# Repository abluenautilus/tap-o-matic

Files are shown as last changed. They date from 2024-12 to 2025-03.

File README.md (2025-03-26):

# Tap-O-Matic

Modification of the delay created by Harry Richardson based on the source code from the Olivia Artz Time Machine

## BOM
 - 9 * Bournes sliders (PTL30-15R0-104B2).
 - 9 * B10K - Song Huei TALL Trimmer Potentiometer with Detent
 - 5 * B10K Alpha vertical 9mm pots with 6.35mm shaft
 - 19 * Thonkicon Mono Jacks
 - 2 * SaleCom ES-4 mini toggle switches
 - 1 * DG408 multiplexer
 - 3 * 4051 multiplexer
 - 9 * 820R resistors (exact value doesn't matter - these set the LED brightness. Anything between about 800 and 1000 ohms should be good).
 - 4 * 16-pin DIP sockets.
 - 5 * 100nF capacitors
 - 1 * Daisy Patch Submodule
 - 4 * 2x5 headers (to connect to the Daisy).
 - 1 * 2x5 power connector (with no shroud - there isn't room!)
 - Knobs to taste :-)

Thonk should be good for the pots, the tall trimmers with detents, and the jacks.

https://www.thonk.co.uk/shop/alpha-9mm-pots/ (B10K, Vertical mount)

https://www.thonk.co.uk/shop/ttpots/ (B10K, Get the ones with the centre detent!)

https://www.thonk.co.uk/shop/thonkiconn/

The hard one is the switches. I got mine from JPR Electronics, where I they call it the "IP67 vertical on-on" switch.

https://www.jprelec.co.uk//categories/components/switches-and-sensors/toggle-switches/salecom-es-40t-ip67-sealed-submin-toggle-switch/product/ip67-toggle-spdt-vertic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

The Daisy Submodule can be bought from Juno. It was actually cheaper to buy it from their Ebay store rather than their own website. Not sure if that's still the case.

https://www.ebay.co.uk/itm/405345530695

The rest are all generally available: Digikey, Mouser, RS, Farnell...

## Front Panel
I got mine made by MeFace in the UK: send an email with an attached PDF or SVG to sales@meface.co.uk for a quote.

The files are available here: https://github.com/cormallen/tap-o-matic/tree/main/panel

## Build Instructions
The components have to be soldered in the right order, since some of the components cover the solder holes of others.

### Back side components.
First solder all the components on the back side of the board:

 - List item
 - IC Sockets
 - Capacitors
 - Resistors (shown on the silkscreen as being on the front, but put them on the back!)
 - Headers
 - Power connector.

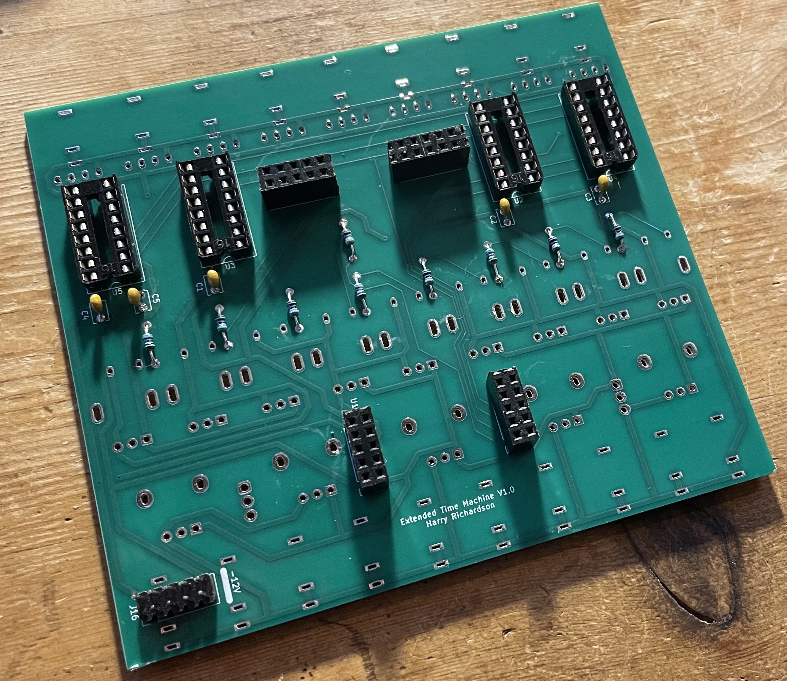
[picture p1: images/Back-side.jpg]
image info


This is how should look when you're done.

 ### Trim the ends

Because the sliders (and two jack sockets) go on top of backside components, you need to trim the ends that poke through to the front side as close to the board as is easily possible (just for those components that go under the sliders and jacks).

### Insulate

Next, we need to put some electrical tape (or other insulator) on the front side, so that the sliders and jacks don't touch any of our solder.

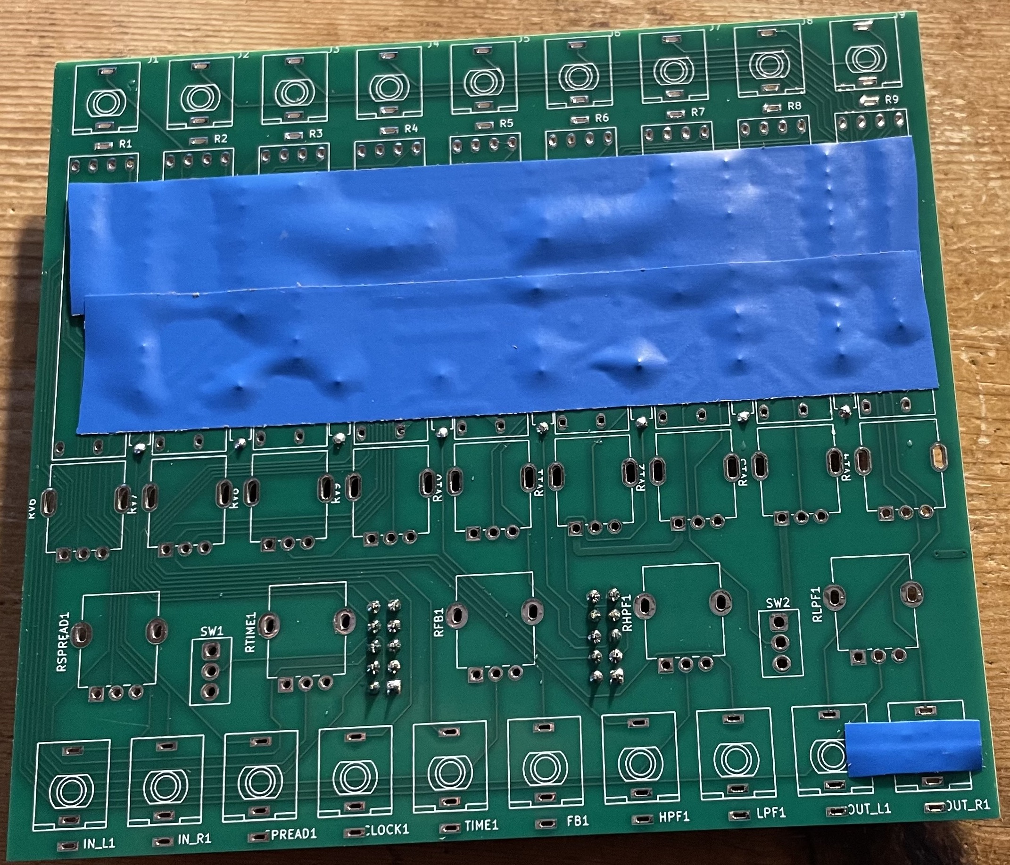
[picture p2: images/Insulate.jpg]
image info


### Jacks and Pan Pots

Place the jacks and pan pots in their holes. Put the front panel on them (to make sure everything is perfectly aligned), do up the nuts on the jacks to hold everything in place and then flip the board over so that you can solder it all in.

For the two jacks that go over the power connector, you may need to trim just a little bit of the plastic (less than 1mm!) out from the sides so that they can fit flush to the board. This can be done with a pair of dikes, a file or a dremmel.

Take the panel back off again.

### Sliders, Pots and Switches.

Place the rest of the front panel hardware on the board, put the front panel on, then flip it over and solder.

Note that the sliders are EXTREMELY close to the pan pots, as I was trying to give as much room for fingers on the main knobs as possible. According to the datasheets, this should have been fine, but **if I did another revision then I would move the pan pots down by 1mm (and update the front panel!)**. Fortunately the sliders actually have a good bit of play in them, so you should be able to get them in fine. (But make sure the pan pots are soldered first, since you need those to be perfectly aligned with the front panel holes).

## Flashing Firmware

You can download the firmware image here: https://github.com/cormallen/tap-o-matic/tree/main/binaries

You can flash the firmware either by setting up VSCode or by using the Web Programmer. VSCode is overkill unless you need a dev environment anyway, or you want to make changes to the code.

Instructions for the Web Programmer method: https://www.youtube.com/watch?v=UaUJ3N8i57c

Instructions for the VSCode method: https://github.com/electro-smith/DaisyWiki/wiki/1.-Setting-Up-Your-Development-Environment

*The video I've linked for the Web Programmer is for QuBit modules, but the process is identical, and that's the simplest explanation I could find.*

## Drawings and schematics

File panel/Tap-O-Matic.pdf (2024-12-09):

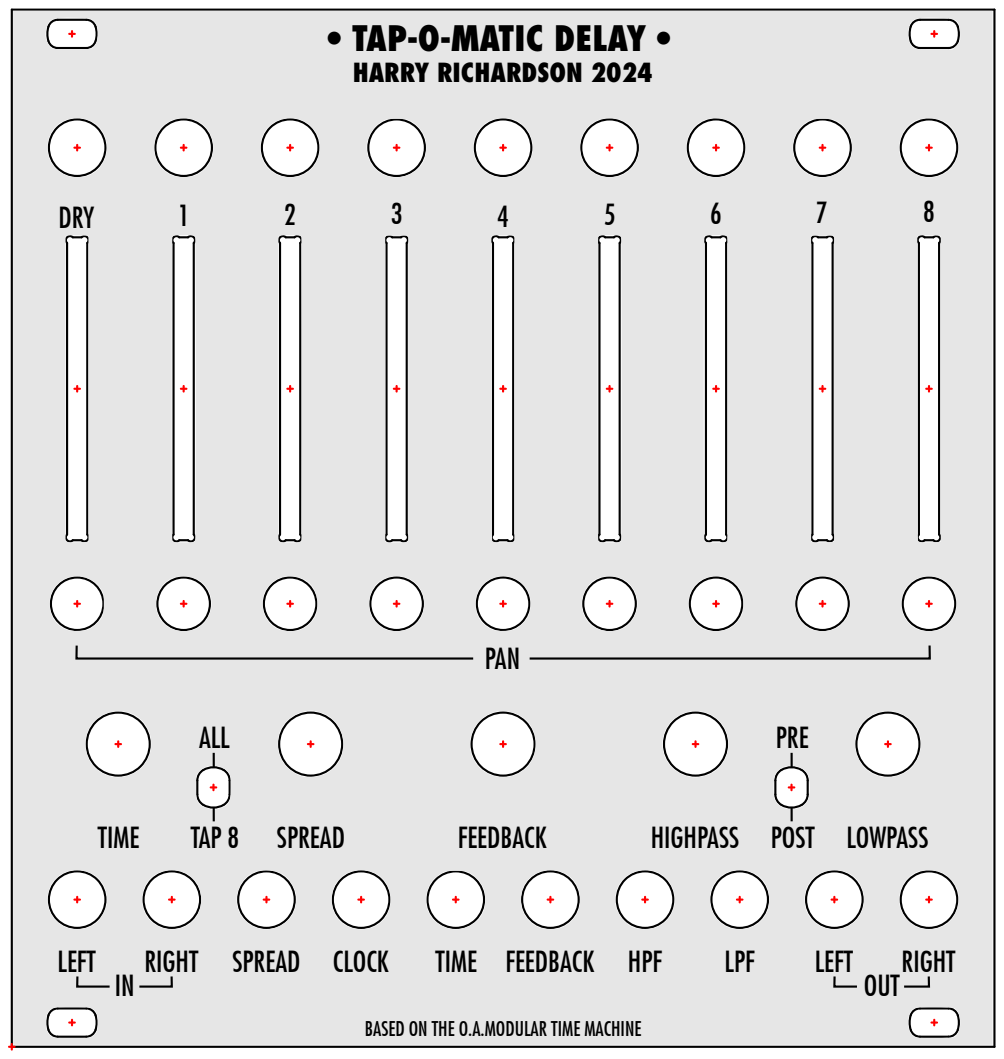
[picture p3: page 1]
PAN; LEFT; RIGHT SPREAD; RIGHT; ALL; TIME; TAP 8; SPREAD; FEEDBACK; HIGHPASS; LOWPASS; CLOCK; FEEDBACK HPF; LPF TIME; OUT; DRY; PRE; POST

• TAP-O-MATIC DELAY •
HARRY RICHARDSON 2024

BASED ON THE O.A.MODULAR TIME MACHINE

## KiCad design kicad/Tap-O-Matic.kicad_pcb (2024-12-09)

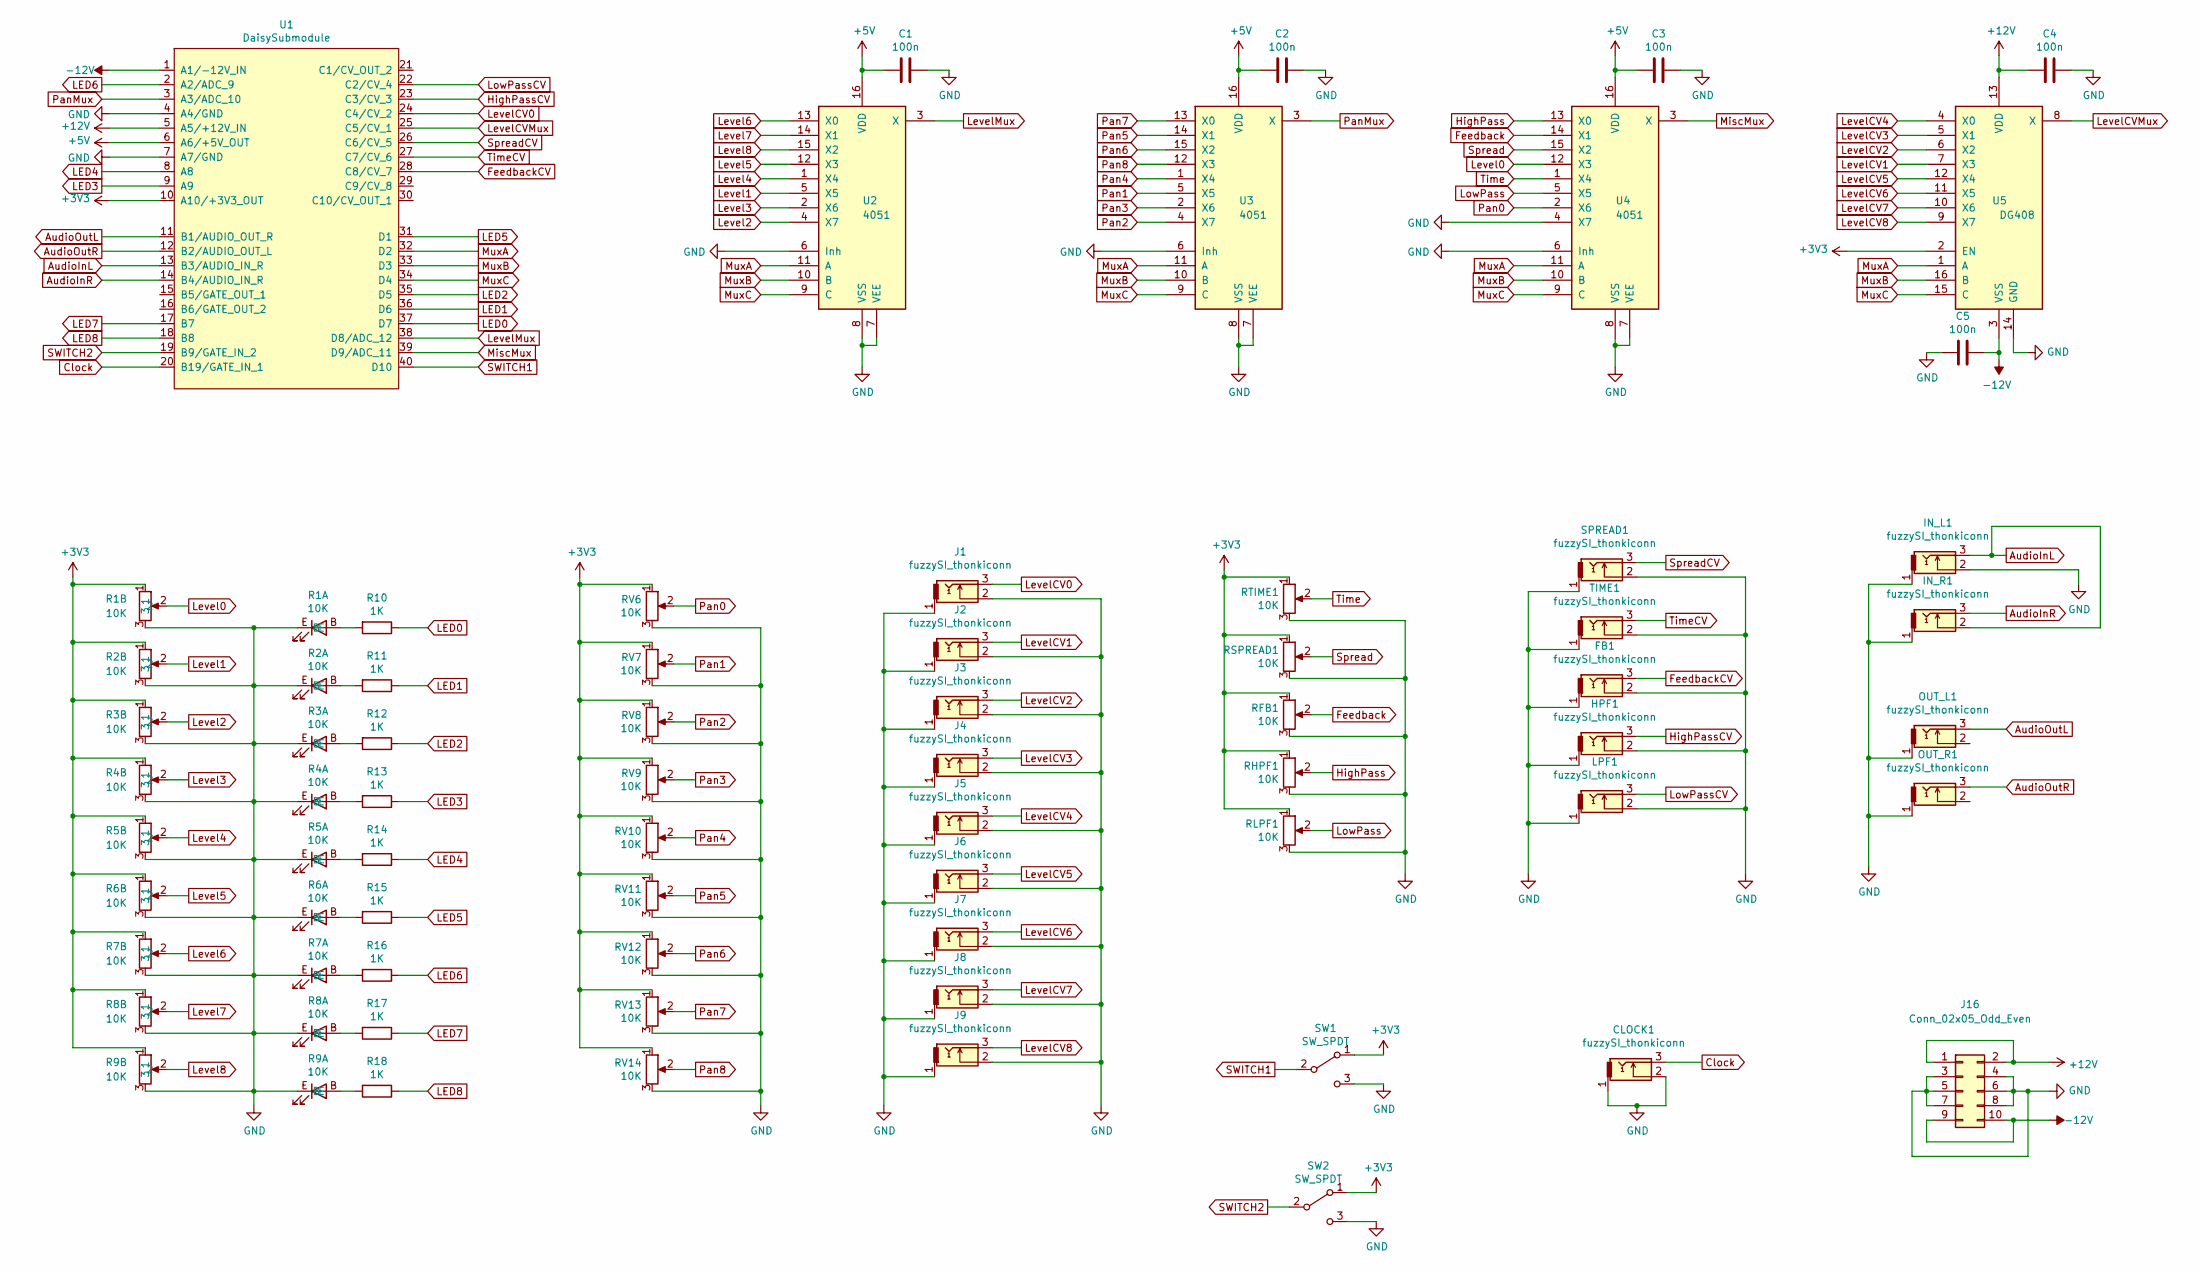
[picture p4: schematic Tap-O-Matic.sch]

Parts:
C1, C2, C3, C4, C5: 100n; C_Disc_D3.8mm_W2.6mm_P2.50mm
CLOCK1: fuzzySI_thonkiconn; thonkiconn_fuzzySi
FB1: fuzzySI_thonkiconn; thonkiconn_fuzzySi
HPF1: fuzzySI_thonkiconn; thonkiconn_fuzzySi
IN_L1: fuzzySI_thonkiconn; thonkiconn_fuzzySi
IN_R1: fuzzySI_thonkiconn; thonkiconn_fuzzySi
J1, J2, J3, J4, J5, J6, J7, J8, J9: fuzzySI_thonkiconn; thonkiconn_fuzzySi
J16: Conn_02x05_Odd_Even; PinHeader_2x05_P2.54mm_Vertical
LPF1: fuzzySI_thonkiconn; thonkiconn_fuzzySi
OUT_L1: fuzzySI_thonkiconn; thonkiconn_fuzzySi
OUT_R1: fuzzySI_thonkiconn; thonkiconn_fuzzySi
R1, R2, R3, R4, R5, R6, R7, R8, R9: 10K; PTL45
R10, R11, R12, R13, R14, R15, R16, R17, R18: 1K; R_Axial_DIN0207_L6.3mm_D2.5mm_P7.62mm_Horizontal
RFB1: 10K; Potentiometer_Alpha_RD901F-40-00D_Single_Vertical
RHPF1: 10K; Potentiometer_Alpha_RD901F-40-00D_Single_Vertical
RLPF1: 10K; Potentiometer_Alpha_RD901F-40-00D_Single_Vertical
RSPREAD1: 10K; Potentiometer_Alpha_RD901F-40-00D_Single_Vertical
RTIME1: 10K; Potentiometer_Alpha_RD901F-40-00D_Single_Vertical
RV6, RV7, RV8, RV9, RV10, RV11, RV12, RV13, RV14: 10K; SongHuei_tall_trimmer
SPREAD1: fuzzySI_thonkiconn; thonkiconn_fuzzySi
SW1, SW2: SW_SPDT; SALECOM_ES4-2_SPDT
TIME1: fuzzySI_thonkiconn; thonkiconn_fuzzySi
U1: DaisySubmodule
U2, U3, U4: 4051; DIP-16_W7.62mm_Socket
U5: DG408; DIP-16_W7.62mm_Socket

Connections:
+3V3: R1.1, R2.1, R3.1, R4.1, R5.1, R6.1, R7.1, R8.1, R9.1, RFB1.1, RHPF1.1, RLPF1.1, RSPREAD1.1, RTIME1.1, RV6.1, RV7.1, RV8.1, RV9.1, RV10.1, RV11.1, RV12.1, RV13.1, RV14.1, SW1.1 (A), SW2.1 (A), U1.10 (A10/+3V3_OUT), U5.2 (EN)
+5V: C1.2, C2.2, C3.2, U1.6 (A6/+5V_OUT), U2.16 (VDD), U3.16 (VDD), U4.16 (VDD)
+12V: C4.2, J16.1, J16.2, U1.5 (A5/+12V_IN), U5.13 (VDD)
-12V: C5.1, J16.9, J16.10, U1.1 (A1/-12V_IN), U5.3 (VSS)
AudioInL: IN_L1.3, IN_R1.2, U1.13 (B3/AUDIO_IN_R)
AudioInR: IN_R1.3, U1.14 (B4/AUDIO_IN_R)
AudioOutL: OUT_L1.3, U1.11 (B1/AUDIO_OUT_R)
AudioOutR: OUT_R1.3, U1.12 (B2/AUDIO_OUT_L)
Clock: CLOCK1.3, U1.20 (B19/GATE_IN_1)
Feedback: RFB1.2, U4.14 (X1)
FeedbackCV: FB1.3, U1.28 (C8/CV_7)
GND: C1.1, C2.1, C3.1, C4.1, C5.2, CLOCK1.1, CLOCK1.2, FB1.1, FB1.2, HPF1.1, HPF1.2, IN_L1.1, IN_L1.2, IN_R1.1, J1.1, J1.2, J2.1, J2.2, J3.1, J3.2, J4.1, J4.2, J5.1, J5.2, J6.1, J6.2, J7.1, J7.2, J8.1, J8.2, J9.1, J9.2, J16.3, J16.4, J16.5, J16.6, J16.7, J16.8, LPF1.1, LPF1.2, OUT_L1.1, OUT_R1.1, R1.3, R1.E, R2.3, R2.E, R3.3, R3.E, R4.3, R4.E, R5.3, R5.E, R6.3, R6.E, R7.3, R7.E, R8.3, R8.E, R9.3, R9.E, RFB1.3, RHPF1.3, RLPF1.3, RSPREAD1.3, RTIME1.3, RV6.3, RV7.3, RV8.3, RV9.3, RV10.3, RV11.3, RV12.3, RV13.3, RV14.3, SPREAD1.1, SPREAD1.2, SW1.3 (C), SW2.3 (C), TIME1.1, TIME1.2, U1.4 (A4/GND), U1.7 (A7/GND), U2.6 (Inh), U2.7 (VEE), U2.8 (VSS), U3.6 (Inh), U3.7 (VEE), U3.8 (VSS), U4.4 (X7), U4.6 (Inh), U4.7 (VEE), U4.8 (VSS), U5.14 (GND)
HighPass: RHPF1.2, U4.13 (X0)
HighPassCV: HPF1.3, U1.23 (C3/CV_3)
LED0: R10.1, U1.37 (D7)
LED1: R11.1, U1.36 (D6)
LED2: R12.1, U1.35 (D5)
LED3: R13.1, U1.9 (A9)
LED4: R14.1, U1.8 (A8)
LED5: R15.1, U1.31 (D1)
LED6: R16.1, U1.2 (A2/ADC_9)
LED7: R17.1, U1.17 (B7)
LED8: R18.1, U1.18 (B8)
Level0: R1.2, U4.12 (X3)
Level1: R2.2, U2.5 (X5)
Level2: R3.2, U2.4 (X7)
Level3: R4.2, U2.2 (X6)
Level4: R5.2, U2.1 (X4)
Level5: R6.2, U2.12 (X3)
Level6: R7.2, U2.13 (X0)
Level7: R8.2, U2.14 (X1)
Level8: R9.2, U2.15 (X2)
LevelCV0: J1.3, U1.24 (C4/CV_2)
LevelCV1: J2.3, U5.7 (X3)
LevelCV2: J3.3, U5.6 (X2)
LevelCV3: J4.3, U5.5 (X1)
LevelCV4: J5.3, U5.4 (X0)
LevelCV5: J6.3, U5.12 (X4)
LevelCV6: J7.3, U5.11 (X5)
LevelCV7: J8.3, U5.10 (X6)
LevelCV8: J9.3, U5.9 (X7)
LevelCVMux: U1.25 (C5/CV_1), U5.8 (X)
LevelMux: U1.38 (D8/ADC_12), U2.3 (X)
LowPass: RLPF1.2, U4.5 (X5)
LowPassCV: LPF1.3, U1.22 (C2/CV_4)
MiscMux: U1.39 (D9/ADC_11), U4.3 (X)
MuxA: U1.32 (D2), U2.11 (A), U3.11 (A), U4.11 (A), U5.1 (A)
MuxB: U1.33 (D3), U2.10 (B), U3.10 (B), U4.10 (B), U5.16 (B)
MuxC: U1.34 (D4), U2.9 (C), U3.9 (C), U4.9 (C), U5.15 (C)
unnamed: R1.B, R10.2
unnamed: R2.B, R11.2
unnamed: R3.B, R12.2
unnamed: R4.B, R13.2
unnamed: R5.B, R14.2
unnamed: R6.B, R15.2
unnamed: R7.B, R16.2
unnamed: R8.B, R17.2
unnamed: R9.B, R18.2
Pan0: RV6.2, U4.2 (X6)
Pan1: RV7.2, U3.5 (X5)
Pan2: RV8.2, U3.4 (X7)
Pan3: RV9.2, U3.2 (X6)
Pan4: RV10.2, U3.1 (X4)
Pan5: RV11.2, U3.14 (X1)
Pan6: RV12.2, U3.15 (X2)
Pan7: RV13.2, U3.13 (X0)
Pan8: RV14.2, U3.12 (X3)
PanMux: U1.3 (A3/ADC_10), U3.3 (X)
SWITCH1: SW1.2 (B), U1.40 (D10)
SWITCH2: SW2.2 (B), U1.19 (B9/GATE_IN_2)
Spread: RSPREAD1.2, U4.15 (X2)
SpreadCV: SPREAD1.3, U1.26 (C6/CV_5)
Time: RTIME1.2, U4.1 (X4)
TimeCV: TIME1.3, U1.27 (C7/CV_6)

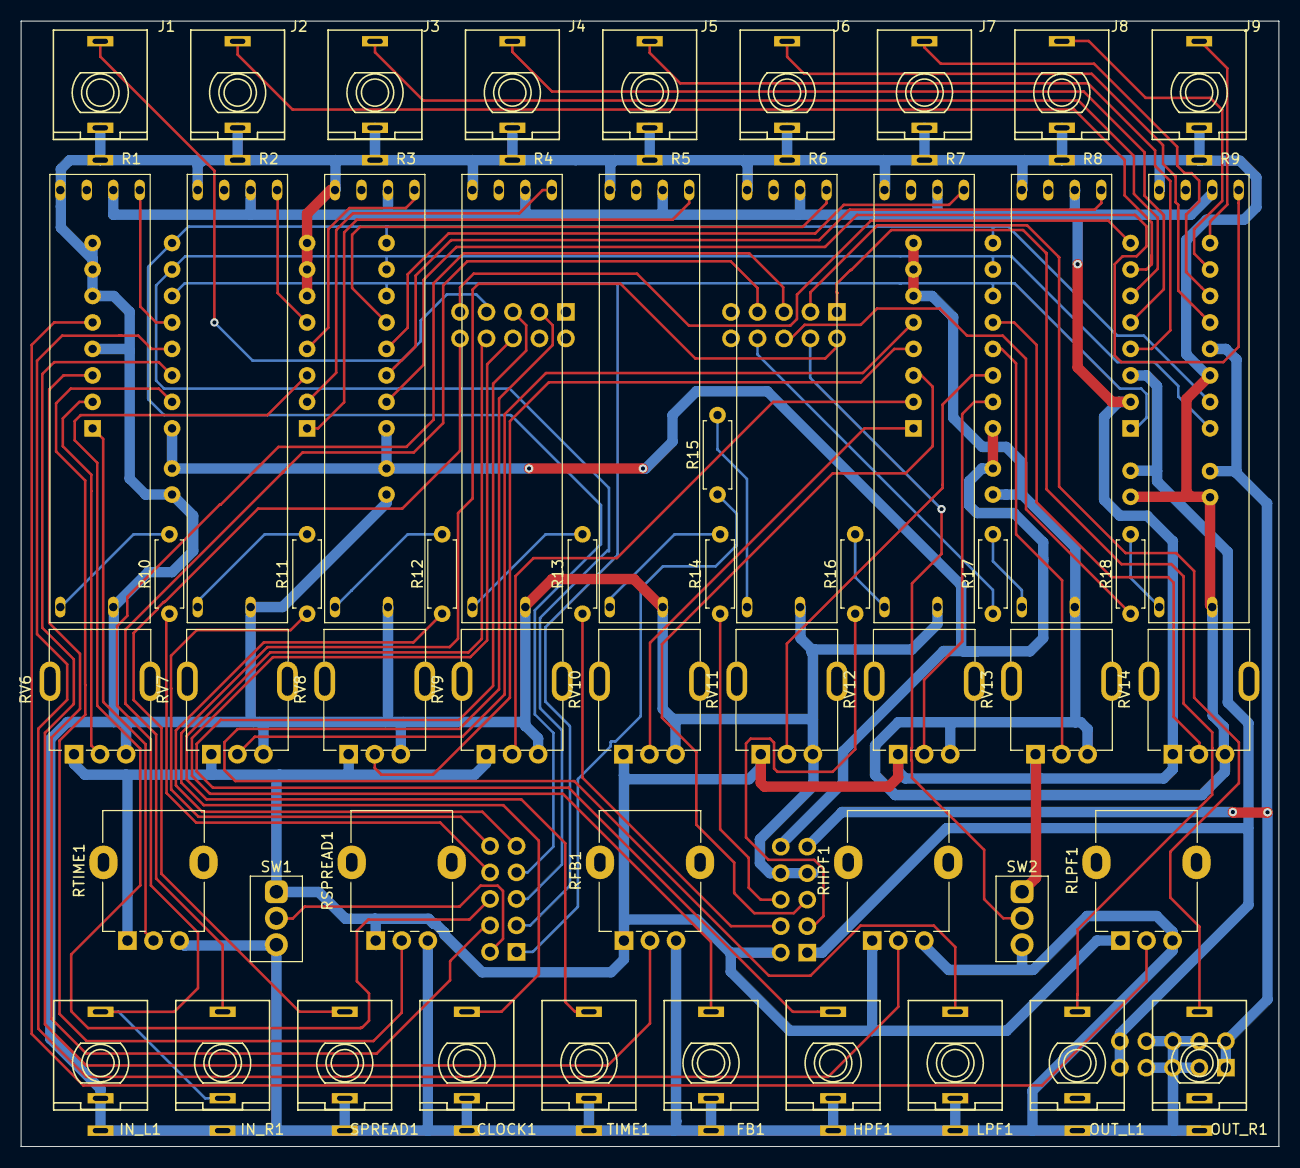
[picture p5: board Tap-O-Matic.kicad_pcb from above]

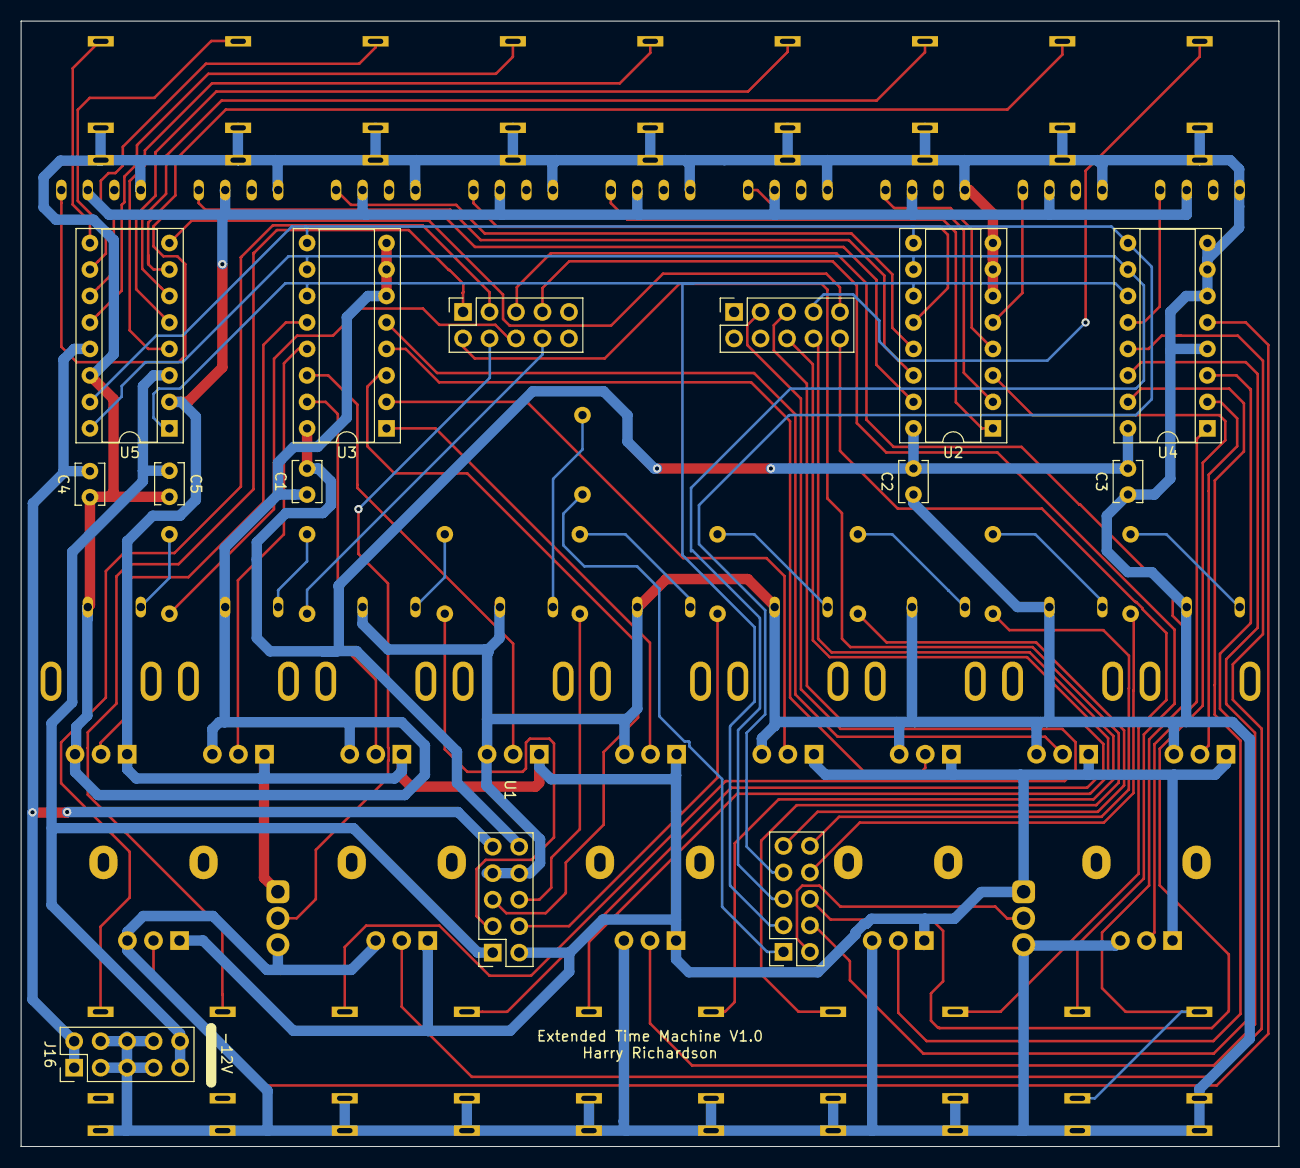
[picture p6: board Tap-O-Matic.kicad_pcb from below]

Board: 2 copper layers, 120.7 x 108.0 mm, 64 parts (11 on the bottom side), 74 nets.

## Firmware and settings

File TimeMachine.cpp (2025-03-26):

#include "daisy_patch_sm.h"
#include "daisysp.h"
#include "dsp.h"
#include "time_machine_hardware.h"

using namespace daisy;
using namespace oam;
using namespace time_machine;
using namespace std;

#define N_TAPS 9
#define TIME_SECONDS 150
#define CALIBRATION_SAMPLES 128
#define BUFFER_WIGGLE_ROOM_SAMPLES 1000

TimeMachineHardware hw;

// Setting Struct containing parameters we want to save to flash
struct CvCalibrationData
{
	float timeCvOffset;
	float spreadCvOffset;
	float feedbackCvOffset;
	float lowpassCvOffset;
	float highpassCvOffset;
	float levelsCvOffset[N_TAPS];

	void Init()
	{
		timeCvOffset = 0.0;
		spreadCvOffset = 0.0;
		feedbackCvOffset = 0.0;
		lowpassCvOffset = 0.0;
		highpassCvOffset = 0.0;

		for (int i = 0 ; i < N_TAPS; i++)
		{
			levelsCvOffset[i] = 0.0;
		}
	}

	// Overloading the != operator
	// This is necessary as this operator is used in the PersistentStorage source code
	bool operator!=(const CvCalibrationData& a) const
	{
		if (a.timeCvOffset != timeCvOffset) 		return true;
		if (a.spreadCvOffset != spreadCvOffset) 	return true;
		if (a.feedbackCvOffset != feedbackCvOffset) return true;
		if (a.lowpassCvOffset != lowpassCvOffset) 	return true;
		if (a.highpassCvOffset != highpassCvOffset) return true;

		for (int i = 0; i < N_TAPS; i++)
		{
			if (a.levelsCvOffset[i] != levelsCvOffset[i]) return true;
		}

		return false;
    }
};


// Gather together all the values and Slew objects we need to handle a control
// consisting of a knob/slider and a CV input (optional).
class ControlHandler
{
public:
	char name[10];

	float cv;
	float cvOffset;
	Slew cvSlew;

	float knob;
	Slew knobSlew;

	float value;

	ControlHandler(const char *dumpName = "")
	{
		strncpy(name, dumpName, 9);

		cv = 0.0;
		cvSlew.Init(0.5, 0.0005);
		cvOffset = 0.0;

		knob = 0.0;
		knobSlew.Init(0.5, 0.0005);

		value = 0.0;
	}

	void SetDumpName(const char *dumpName)
	{
		strncpy(name, dumpName, sizeof(name));
	}

	void Dump()
	{
		hw.PrintLine(
			"%-10s   value:" FLT_FMT(5) "   knob:" FLT_FMT(5) "   cv:" FLT_FMT(5) "   offset:" FLT_FMT(5),
			name,
			FLT_VAR(5, value),
			FLT_VAR(5, knob),
			FLT_VAR(5, cv),
			FLT_VAR(5, cvOffset));
	}
};


// init buffers - add an extra second just in case we somehow end up slightly beyond max time
// due to precision loss in floating point arithmetic (maybe use doubles for time values???)
float DSY_SDRAM_BSS bufferLeft[48000 * TIME_SECONDS + BUFFER_WIGGLE_ROOM_SAMPLES];
float DSY_SDRAM_BSS bufferRight[48000 * TIME_SECONDS + BUFFER_WIGGLE_ROOM_SAMPLES];

ControlHandler time("time");
ControlHandler feedback("feedback");
ControlHandler spread("spread");
ControlHandler highpass("highpass");
ControlHandler lowpass("lowpass");
ControlHandler levels[N_TAPS];
ControlHandler pans[N_TAPS];

PersistentStorage<CvCalibrationData> CalibrationDataStorage(hw.qspi);
GateIn gate;
Led leds[N_TAPS];
GPIO feedbackModeSwitch;
GPIO filterPositionSwitch;

StereoTimeMachine timeMachine;
ClockRateDetector clockRateDetector;
ContSchmidt timeKnobSchmidt;
ContSchmidt timeCvSchmidt;

// delay setting LEDs for startup sequences
bool setLeds = false;

// Performance metrics.
CpuLoadMeter cpuMeter;
int droppedFrames = 0;


void updateControlHandlers()
{
	// condition feedback knob to have deadzone in the middle, add CV
	feedback.knob = fourPointWarp(1.0 - minMaxKnob(hw.GetFeedbackKnob(), 0.028));
	feedback.cv = clamp(hw.GetAdcValue(FEEDBACK_CV) - feedback.cvOffset, -1.0, 1.0);
	feedback.value = clamp(fourPointWarp(feedback.knobSlew.Process(feedback.knob)) * 2.0 + feedback.cvSlew.Process(feedback.cv), 0, 3);

	// condition spread knob value to have deadzone in the middle, add CV
	spread.knob = fourPointWarp(1.0 - minMaxKnob(hw.GetSpreadKnob(), 0.0008));
	spread.cv = clamp(hw.GetAdcValue(SPREAD_CV) - spread.cvOffset, -1.0, 1.0);
	spread.value = fourPointWarp(spread.knobSlew.Process(spread.knob)) + spread.cvSlew.Process(spread.cv);

	lowpass.knob = 1.0f - hw.GetLowpassKnob();
	lowpass.cv = clamp(hw.GetAdcValue(LOWPASS_CV) - lowpass.cvOffset, -1.0, 1.0);
	//lowpass.value = clamp(lowpass.knobSlew.Process(lowpass.knob) + lowpass.cvSlew.Process(lowpass.cv), 0.001, 1.0) / 2.0;
	lowpass.value = clamp(lowpass.knobSlew.Process(lowpass.knob) + lowpass.cvSlew.Process(lowpass.cv), 0.001, 1.0);
	lowpass.value = (exp(lowpass.value * 3.0) - 1.0) / (1.72 * 22.2);

	highpass.knob = 1.0f - hw.GetHighpassKnob();
	highpass.cv = clamp(hw.GetAdcValue(HIGHPASS_CV) - highpass.cvOffset, -1.0, 1.0);
	//highpass.value = clamp(highpass.knobSlew.Process(highpass.knob) + highpass.cvSlew.Process(highpass.cv), 0.001, 1.0) / 2.0;
	highpass.value = clamp(highpass.knobSlew.Process(highpass.knob) + highpass.cvSlew.Process(highpass.cv), 0.001, 1.0);
	highpass.value = (exp(highpass.value * 3.0) - 1.0) / (1.72 * 22.2);

	// Handle the levels and pans.
	for (int i = 0; i < N_TAPS; i++)
	{
		ControlHandler &s = levels[i];
		s.knob = minMaxSlider(1.0 - hw.GetLevelSlider(i));
		s.cv = clamp((hw.GetLevelCV(i)) - s.cvOffset, -1.0, 1.0);
		s.value = clamp(s.knobSlew.Process(s.knob) + s.cvSlew.Process(s.cv), 0.0, 1.0);

		ControlHandler &p = pans[i];
		p.knob = hw.GetPanKnob(i);
		p.value = clamp(p.knobSlew.Process(p.knob), -1.0, 1.0);
	}

	// Handle the time stuff, which is a bit more involved.

	time.knob = minMaxKnob(1.0 - hw.GetTimeKnob(), 0.0008);
	time.cv = clamp(hw.GetAdcValue(TIME_CV) - time.cvOffset, -1.0, 1.0);

	// calculate time based on clock if present, otherwise simple time
	time.value = 0.0;
	if (clockRateDetector.GetInterval() > 0.0)
	{
		// 12 quantized steps for knob, 10 for CV (idk what these quanta should actually be)
		// time doubles and halves with each step, they are additive/subtractive
		float timeCoef = pow(2.0, (timeKnobSchmidt.Process((1.0 - time.knob) * 12)) + (timeCvSchmidt.Process(time.cv * 10))) / pow(2.0, 6.0);
		time.value = clockRateDetector.GetInterval() / timeCoef;

		// make sure time is a power of two less than the max time available in the buffer
		while(time.value > TIME_SECONDS) time.value *= 0.5;
	}
	else
	{
		// time linear with knob, scaled v/oct style with CV
		time.value = pow(time.knobSlew.Process(time.knob), 2.0) * 8.0 / pow(2.0, time.cvSlew.Process(time.cv) * 5.0);
	}

	// force time down to a max value (taking whichever is lesser, the max or the time)
	time.value = std::min((float)TIME_SECONDS, time.value);
}


// called every N samples (search for SetAudioBlockSize)
void audioCallback(AudioHandle::InputBuffer in, AudioHandle::OutputBuffer out, size_t size)
{
	// cpu meter measurements start
	cpuMeter.OnBlockStart();
	droppedFrames++;

	// process controls at the ADC level.
	hw.ProcessAllControls();

	// Then we can use those values when updating our handlers.
	updateControlHandlers();

	for (int i = 1; i < N_TAPS; i++)
	{
		// set LEDs based on loudness for last 8 sliders
		float loudness = timeMachine.timeMachineLeft.readHeads[i - 1].loudness.Get();
		loudness = max(loudness, timeMachine.timeMachineRight.readHeads[i - 1].loudness.Get());
		if (setLeds)
		{
			leds[i].Set(loudness);
			leds[i].Update();
		}
	}

	// set LEDs based on loudness for first slider
	float loudness = timeMachine.timeMachineLeft.loudness.Get();
	loudness = max(loudness, timeMachine.timeMachineRight.loudness.Get());
	if (setLeds)
	{
		leds[0].Set(loudness);
		leds[0].Update();
	}

	// set time machine dry slider value, feedback, "blur" which is semi-deprecated
	timeMachine.Set(levels[0].value, feedback.value, feedback.value, highpass.value, lowpass.value, feedbackModeSwitch.Read(), filterPositionSwitch.Read());

	for (int i = 1; i < N_TAPS; i++)
	{
		float leftPan, rightPan;
		panToVolume(hw.GetPanKnob(i), &leftPan, &rightPan);

		// let last 8 slider time/amp/blur values for left channel time machine instance
        timeMachine.timeMachineLeft.readHeads[i - 1].Set(
            spreadTaps((i / (float) (N_TAPS - 1)), spread.value) * time.value,
            leftPan * levels[i].value,
			max(0.0, feedback.value - 1.0)
        );

		// let last 8 slider time/amp/blur values for right channel time machine instance
		timeMachine.timeMachineRight.readHeads[i - 1].Set(
            spreadTaps((i / (float) (N_TAPS - 1)), spread.value) * time.value,
            rightPan * levels[i].value,
			max(0.0, feedback.value -1.0)
        );
	}

	for (size_t i = 0; i < size; i++)
	{
		// process gate for clock rate detector at audio rate (per-sample) so it calculates clock correctly
		clockRateDetector.Process(hw.gate_in_1.State());

		// process input into time machine
		float* output = timeMachine.Process(in[0][i], in[1][i]);

		// set hardware output to time machine output
		out[0][i] = output[0];
		out[1][i] = output[1];
	}

	//cpu meter measurement stop
	cpuMeter.OnBlockEnd();
	droppedFrames--;
}


bool isCvCloseToZero(float val)
{
	return (val > -0.03) && (val < 0.03);
}


bool shouldCalibrate()
{
	hw.PrintLine("Considering calibration:");

	if (!hw.gate_in_1.State()) return false;

	if (!isCvCloseToZero(hw.GetAdcValue(SPREAD_CV))) 	return false;
	if (!isCvCloseToZero(hw.GetAdcValue(TIME_CV))) 		return false;
	if (!isCvCloseToZero(hw.GetAdcValue(FEEDBACK_CV))) 	return false;
	if (!isCvCloseToZero(hw.GetAdcValue(HIGHPASS_CV))) 	return false;
	if (!isCvCloseToZero(hw.GetAdcValue(LOWPASS_CV))) 	return false;
	if (!isCvCloseToZero(hw.GetAdcValue(LEVEL_DRY_CV))) return false;

	if (minMaxKnob(1.0 - hw.GetTimeKnob()) < 0.95) 		return false;
	if (minMaxKnob(1.0 - hw.GetSpreadKnob()) < 0.95) 	return false;
	if (minMaxKnob(1.0 - hw.GetFeedbackKnob()) < 0.95) 	return false;
	if (minMaxKnob(1.0 - hw.GetLowpassKnob()) < 0.95) 	return false;
	if (minMaxKnob(1.0 - hw.GetHighpassKnob()) < 0.95) 	return false;

	for (int i = 0; i < N_TAPS; i++)
	{
		if (!isCvCloseToZero(hw.GetLevelCV(i))) 				return false;
		if (minMaxSlider(1.0 - hw.GetLevelSlider(i)) < 0.95) 	return false;
	}

	return true;
}


void calibrate(CvCalibrationData &saved, int ledSeqDelay)
{
	// do reverse LED startup sequence while
	// checking that we definitely want to calibrate
	for (int i = 0; i < (5000 / ledSeqDelay); i++)
	{
		for (int j = 0; j < N_TAPS; j++)
		{
			leds[j].Set(j == ((N_TAPS - 1) - (i % N_TAPS)) ? 1.0 : 0.0);
			leds[j].Update();
		}

		System::Delay(ledSeqDelay);
		if (!shouldCalibrate()) return;
	}

	saved.Init();

	hw.PrintLine("Starting calibration");

	// perform calibration routine
	for (int i = 0; i < CALIBRATION_SAMPLES; i++)
	{
		// accumulate cv values
		saved.timeCvOffset += time.cv;
		saved.spreadCvOffset += spread.cv;
		saved.feedbackCvOffset += feedback.cv;
		saved.lowpassCvOffset += lowpass.cv;
		saved.highpassCvOffset += highpass.cv;

		for (int j = 0; j < N_TAPS; j++)
		{
			saved.levelsCvOffset[j] += levels[j].cv;
		}

		// wait 10ms
		System::Delay(10);

		// set LEDs
		for (int ledIndex = 0; ledIndex < N_TAPS; ledIndex++)
		{
			leds[ledIndex].Set(i % (N_TAPS - 1) < 4 ? 1.0f : 0.0f);
			leds[ledIndex].Update();
		}
	}

	// divide CVs by number of samples taken to get average

	float n = (float) CALIBRATION_SAMPLES;
	saved.timeCvOffset = saved.timeCvOffset / n;
	saved.spreadCvOffset = saved.spreadCvOffset / n;
	saved.feedbackCvOffset = saved.feedbackCvOffset / n;
	saved.lowpassCvOffset = saved.lowpassCvOffset / n;
	saved.highpassCvOffset = saved.highpassCvOffset / n;

	for (int i = 0; i < N_TAPS; i++)
	{
		saved.levelsCvOffset[i] = saved.levelsCvOffset[i] / n;
	}

	// save calibration data
	CalibrationDataStorage.Save();
}

void logState()
{
	hw.PrintLine("CPU AVG: " FLT_FMT(6), FLT_VAR(6, cpuMeter.GetAvgCpuLoad()));
	hw.PrintLine("CPU MIN: " FLT_FMT(6), FLT_VAR(6, cpuMeter.GetMinCpuLoad()));
	hw.PrintLine("CPU MAX: " FLT_FMT(6), FLT_VAR(6, cpuMeter.GetMaxCpuLoad()));
	hw.PrintLine("DROPPED FRAMES: %d", droppedFrames);

	hw.PrintLine("");

	hw.PrintLine("clock: %s", hw.gate_in_1.State() ? "on" : "off");

	spread.Dump();
	time.Dump();
	feedback.Dump();
	highpass.Dump();
	lowpass.Dump();

	hw.PrintLine("");

	for (int i = 0; i < N_TAPS; i++)
	{
		levels[i].Dump();
	}

	hw.PrintLine("");

	for (int i = 0; i < N_TAPS; i++)
	{
		pans[i].Dump();
	}

	hw.PrintLine("");
}


int main(void)
{
	// init time machine hardware
    hw.Init();
	hw.StartLog();

	hw.SetAudioBlockSize(7); // number of samples handled per callback

	Pin gatePin = CLOCK;
	gate.Init(gatePin);

	// initialize LEDs
	leds[0].Init(LED_DRY, false);
	leds[1].Init(LED_1, false);
	leds[2].Init(LED_2, false);
	leds[3].Init(LED_3, false);
	leds[4].Init(LED_4, false);
	leds[5].Init(LED_5, false);
	leds[6].Init(LED_6, false);
	leds[7].Init(LED_7, false);
	leds[8].Init(LED_8, false);

	for (int i = 0; i < N_TAPS; i++)
	{
		char buf[10];
		sprintf(buf, "pan_%d", i);
		pans[i].SetDumpName(buf);

		sprintf(buf, "level_%d", i);
		levels[i].SetDumpName(buf);
	}

  	// Initialize our switch.
  	feedbackModeSwitch.Init(FEEDBACK_MODE_SWITCH, GPIO::Mode::INPUT, GPIO::Pull::PULLUP);
	filterPositionSwitch.Init(FILTER_POSITION_SWITCH, GPIO::Mode::INPUT, GPIO::Pull::PULLUP);

	// set sample rate
	hw.SetAudioSampleRate(SaiHandle::Config::SampleRate::SAI_48KHZ);

	// init clock rate detector
	clockRateDetector.Init(hw.AudioSampleRate());

	// init time machine
    timeMachine.Init(hw.AudioSampleRate(), TIME_SECONDS + (((float) BUFFER_WIGGLE_ROOM_SAMPLES) * 0.5 / hw.AudioSampleRate()), bufferLeft, bufferRight);

	// load calibration data, using sensible defaults
	CvCalibrationData defaults;
	defaults.Init();

	CalibrationDataStorage.Init(defaults);
	CvCalibrationData &savedCalibrationData = CalibrationDataStorage.GetSettings();

	// init cpu meter
	cpuMeter.Init(hw.AudioSampleRate(), hw.AudioBlockSize());

	// start time machine hardware audio and logging
    hw.StartAudio(audioCallback);

	// LED startup sequence
	int ledSeqDelay = 100;
	for(int i = 0; i < N_TAPS; i++)
	{
		for(int j = 0; j < N_TAPS; j++)
		{
			leds[j].Set(j == i ? 1.0 : 0.0);
			leds[j].Update();
		}

		System::Delay(ledSeqDelay);
	}

	if (shouldCalibrate())
	{
		calibrate(savedCalibrationData, ledSeqDelay);
	}

	time.cvOffset = savedCalibrationData.timeCvOffset;
	spread.cvOffset = savedCalibrationData.spreadCvOffset;
	feedback.cvOffset = savedCalibrationData.feedbackCvOffset;
	highpass.cvOffset = savedCalibrationData.highpassCvOffset;
	lowpass.cvOffset = savedCalibrationData.lowpassCvOffset;

	for (int i = 0; i < N_TAPS; i++)
	{
		levels[i].cvOffset = savedCalibrationData.levelsCvOffset[i];
	}

	setLeds = true;

	while (true)
	{
		logState();
		System::Delay(333);
	}
}

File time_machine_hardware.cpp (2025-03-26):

#include "time_machine_hardware.h"
#include <vector>

namespace oam
{
namespace time_machine
{
    /** Const definitions */
    constexpr Pin DUMMYPIN        = Pin(PORTX, 0);
    constexpr Pin PIN_ADC_CTRL_1  = DaisyPatchSM::C5;
    constexpr Pin PIN_ADC_CTRL_2  = DaisyPatchSM::C4;
    constexpr Pin PIN_ADC_CTRL_3  = DaisyPatchSM::C3;
    constexpr Pin PIN_ADC_CTRL_4  = DaisyPatchSM::C2;
    constexpr Pin PIN_ADC_CTRL_5  = DaisyPatchSM::C6;
    constexpr Pin PIN_ADC_CTRL_6  = DaisyPatchSM::C7;
    constexpr Pin PIN_ADC_CTRL_7  = DaisyPatchSM::C8;
    constexpr Pin PIN_ADC_CTRL_8  = DaisyPatchSM::C9;
    constexpr Pin PIN_ADC_CTRL_9  = DaisyPatchSM::A2;
    constexpr Pin PIN_ADC_CTRL_10 = DaisyPatchSM::A3;
    constexpr Pin PIN_ADC_CTRL_11 = DaisyPatchSM::D9;
    constexpr Pin PIN_ADC_CTRL_12 = DaisyPatchSM::D8;
    constexpr Pin PIN_USER_LED    = Pin(PORTC, 7);

    constexpr Pin kPinMap[4][10] =
        // Bank A
        {{DaisyPatchSM::A1,
          DaisyPatchSM::A2,
          DaisyPatchSM::A3,
          DaisyPatchSM::A4,
          DaisyPatchSM::A5,
          DaisyPatchSM::A6,
          DaisyPatchSM::A7,
          DaisyPatchSM::A8,
          DaisyPatchSM::A9,
          DaisyPatchSM::A10},

         // Bank B
         {DaisyPatchSM::B1,
          DaisyPatchSM::B2,
          DaisyPatchSM::B3,
          DaisyPatchSM::B4,
          DaisyPatchSM::B5,
          DaisyPatchSM::B6,
          DaisyPatchSM::B7,
          DaisyPatchSM::B8,
          DaisyPatchSM::B9,
          DaisyPatchSM::B10},

         // Bank C
         {DaisyPatchSM::C1,
          DaisyPatchSM::C2,
          DaisyPatchSM::C3,
          DaisyPatchSM::C4,
          DaisyPatchSM::C5,
          DaisyPatchSM::C6,
          DaisyPatchSM::C7,
          DaisyPatchSM::C8,
          DaisyPatchSM::C9,
          DaisyPatchSM::C10},

         // Bank D
         {DaisyPatchSM::D1,
          DaisyPatchSM::D2,
          DaisyPatchSM::D3,
          DaisyPatchSM::D4,
          DaisyPatchSM::D5,
          DaisyPatchSM::D6,
          DaisyPatchSM::D7,
          DaisyPatchSM::D8,
          DaisyPatchSM::D9,
          DaisyPatchSM::D10}};

    const Pin TimeMachineHardware::A1  = kPinMap[0][0];
    const Pin TimeMachineHardware::A2  = kPinMap[0][1];
    const Pin TimeMachineHardware::A3  = kPinMap[0][2];
    const Pin TimeMachineHardware::A4  = kPinMap[0][3];
    const Pin TimeMachineHardware::A5  = kPinMap[0][4];
    const Pin TimeMachineHardware::A6  = kPinMap[0][5];
    const Pin TimeMachineHardware::A7  = kPinMap[0][6];
    const Pin TimeMachineHardware::A8  = kPinMap[0][7];
    const Pin TimeMachineHardware::A9  = kPinMap[0][8];
    const Pin TimeMachineHardware::A10 = kPinMap[0][9];
    const Pin TimeMachineHardware::B1  = kPinMap[1][0];
    const Pin TimeMachineHardware::B2  = kPinMap[1][1];
    const Pin TimeMachineHardware::B3  = kPinMap[1][2];
    const Pin TimeMachineHardware::B4  = kPinMap[1][3];
    const Pin TimeMachineHardware::B5  = kPinMap[1][4];
    const Pin TimeMachineHardware::B6  = kPinMap[1][5];
    const Pin TimeMachineHardware::B7  = kPinMap[1][6];
    const Pin TimeMachineHardware::B8  = kPinMap[1][7];
    const Pin TimeMachineHardware::B9  = kPinMap[1][8];
    const Pin TimeMachineHardware::B10 = kPinMap[1][9];
    const Pin TimeMachineHardware::C1  = kPinMap[2][0];
    const Pin TimeMachineHardware::C2  = kPinMap[2][1];
    const Pin TimeMachineHardware::C3  = kPinMap[2][2];
    const Pin TimeMachineHardware::C4  = kPinMap[2][3];
    const Pin TimeMachineHardware::C5  = kPinMap[2][4];
    const Pin TimeMachineHardware::C6  = kPinMap[2][5];
    const Pin TimeMachineHardware::C7  = kPinMap[2][6];
    const Pin TimeMachineHardware::C8  = kPinMap[2][7];
    const Pin TimeMachineHardware::C9  = kPinMap[2][8];
    const Pin TimeMachineHardware::C10 = kPinMap[2][9];
    const Pin TimeMachineHardware::D1  = kPinMap[3][0];
    const Pin TimeMachineHardware::D2  = kPinMap[3][1];
    const Pin TimeMachineHardware::D3  = kPinMap[3][2];
    const Pin TimeMachineHardware::D4  = kPinMap[3][3];
    const Pin TimeMachineHardware::D5  = kPinMap[3][4];
    const Pin TimeMachineHardware::D6  = kPinMap[3][5];
    const Pin TimeMachineHardware::D7  = kPinMap[3][6];
    const Pin TimeMachineHardware::D8  = kPinMap[3][7];
    const Pin TimeMachineHardware::D9  = kPinMap[3][8];
    const Pin TimeMachineHardware::D10 = kPinMap[3][9];

    /** outside of class static buffer(s) for DMA access */
    uint16_t DMA_BUFFER_MEM_SECTION dsy_patch_sm_dac_buffer[2][48];

    class TimeMachineHardware::Impl
    {
      public:
        Impl()
        {
            dac_running_            = false;
            dac_buffer_size_        = 48;
            dac_output_[0]          = 0;
            dac_output_[1]          = 0;
            internal_dac_buffer_[0] = dsy_patch_sm_dac_buffer[0];
            internal_dac_buffer_[1] = dsy_patch_sm_dac_buffer[1];
        }

        void InitDac();

        void StartDac(DacHandle::DacCallback callback);

        void StopDac();
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

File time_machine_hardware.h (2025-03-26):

#pragma once

#define BODGE false

#include "daisy.h"
#include "daisy_patch_sm.h"

using namespace daisy;
using namespace patch_sm;

#define LED_DRY DaisyPatchSM::D7
#define LED_1 DaisyPatchSM::D6
#define LED_2 DaisyPatchSM::D5
#define LED_3 DaisyPatchSM::A9
#define LED_4 DaisyPatchSM::A8
#define LED_5 DaisyPatchSM::D1
#define LED_6 DaisyPatchSM::A2
#define LED_7 DaisyPatchSM::B7
#define LED_8 DaisyPatchSM::B8

#define CLOCK DaisyPatchSM::B10
#define FEEDBACK_MODE_SWITCH DaisyPatchSM::D10
#define FILTER_POSITION_SWITCH DaisyPatchSM::B9

#define MUX_A DaisyPatchSM::D2
#define MUX_B DaisyPatchSM::D3
#define MUX_C DaisyPatchSM::D4

#define LEVEL_CV_MUX CV_1
#define PAN_MUX ADC_10
#define LEVEL_MUX ADC_11
#define MISC_MUX ADC_12

#define LEVEL_DRY_CV CV_2
#define HIGHPASS_CV CV_3
#define LOWPASS_CV CV_4
#define SPREAD_CV CV_5
#define TIME_CV CV_6
#define FEEDBACK_CV CV_7



namespace oam
{
namespace time_machine
{
    /** Accessors for the Analog Controls.
     *  These cover the 8x Bipolar CV inputs
     *  as well as the 4x 0-3V3 ADC inputs on
     *  the hardware
     *
     *  When reading a value with TimeMachineHardware::GetAdcValue()
     *
     *  patch.GetAdcValue(patch_sm::CV_1);
     */

    /*
    enum
    {
        CV_1 = 0,
        CV_2,
        CV_3,
        CV_4,
        CV_5,
        CV_6,
        CV_7,
        CV_8,
        ADC_9,
        ADC_10,
        ADC_11,
        ADC_12,
        ADC_LAST,
    };*/

    /** Enum for addressing the CV Outputs via the WriteCvOut function. */
    /*
    enum
    {
        CV_OUT_BOTH = 0,
        CV_OUT_1,
        CV_OUT_2,
    };*/


    /** @brief Board support file for TimeMachineHardware hardware
     *  @author shensley
     *  @ingroup boards
     *
     *  Daisy Patch SM is a complete Eurorack module DSP engine.
     *  Based on the Daisy Seed, with circuits added for
     *  interfacing directly with eurorack modular synthesizers.
     */
    class TimeMachineHardware
    {
      public:
        /** Helper for mapping pins, and accessing them using the `GetPin` function */
        enum class PinBank
        {
            A,
            B,
            C,
            D
        };

        TimeMachineHardware() {}
        ~TimeMachineHardware() {}

        /** Initializes the memories, and core peripherals for the Daisy Patch SM */
        void Init();

        /** Starts a non-interleaving audio callback */
        void StartAudio(AudioHandle::AudioCallback cb);

        /** Starts an interleaving audio callback */
        void StartAudio(AudioHandle::InterleavingAudioCallback cb);

        /** Changes the callback that is executing.
         *  This may cause clicks if done while audio is processing.
         */
        void ChangeAudioCallback(AudioHandle::AudioCallback cb);

        /** Changes the callback that is executing.
         *  This may cause clicks if done while audio is processing.
         */
        void ChangeAudioCallback(AudioHandle::InterleavingAudioCallback cb);

        /** Stops the transmission of audio. */
        void StopAudio();

        /** Sets the number of samples processed in an audio callback.
         *  This will only take effect on the next invocation of `StartAudio`
         */
        void SetAudioBlockSize(size_t size);

        /** Sets the samplerate for the audio engine
         *  This will set it to the closest valid samplerate. Options being:
         *  8kHz, 16kHz, 32kHz, 48kHz, and 96kHz
         */
        void SetAudioSampleRate(float sr);

        void SetAudioSampleRate(SaiHandle::Config::SampleRate sample_rate);

        /** Returns the number of samples processed in an audio callback */
        size_t AudioBlockSize();

        /** Returns the audio engine's samplerate in Hz */
        float AudioSampleRate();

        /** Returns the rate at which the audio callback will be called in Hz */
        float AudioCallbackRate();

        /** Starts the Control ADCs
         *
         *  This is started automatically when Init() is called.
         */
        void StartAdc();

        /** Stops the Control ADCs */
        void StopAdc();

        /** Reads and filters all of the analog control inputs */
        void ProcessAnalogControls();

        /** Reads and debounces any of the digital control inputs
         *  This does nothing on this board at this time.
         */
        void ProcessDigitalControls();

        /** Does both of the above */
        void ProcessAllControls()
        {
            ProcessAnalogControls();
            ProcessDigitalControls();
        }

        /** Returns the current value for one of the ADCs */
        float GetAdcValue(int idx);

        float GetLevelSlider(int idx);
        float GetLevelCV(int idx);
        float GetPanKnob(int idx);
        float GetSpreadKnob();
        float GetTimeKnob();
        float GetFeedbackKnob();
        float GetHighpassKnob();
        float GetLowpassKnob();
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

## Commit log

2024-12-09 First commit of changes to the original TimeMachine
    [Tap-O-Matic.kicad_pcb, Tap-O-Matic.sch]
2024-12-16 Added forgottern lib file for kicad
2025-03-26 updated pin code for new libdaisy
